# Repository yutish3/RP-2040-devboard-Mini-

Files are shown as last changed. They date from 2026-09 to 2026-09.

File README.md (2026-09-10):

### ABOUT 
rp-2040 dev board in small form factor of 3cm x 6cm made in kicad

it has :- 2 x 20 pin connectors , separate headers for HC - 05 Bluetooth module , extra 4Mb flash memory , USB c port , 2 buttons for BOOT and Reset and TC2030 connector for programming without usb c

# IMAGES

# SCHEMATICS 



# FOOTPRINTS



# PCB



# RENDER

Initially i tried to make it black but it changed color to smth random and it looks way cooler now 






# FILES
/Production folder has all the production files

/PCB files has all the pcb project files in it

# CREDITS

Kicad

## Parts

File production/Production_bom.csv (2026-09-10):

Designator | Footprint | Quantity | Value | LCSC Part #
C1, C2 | 0201 | 2 | 10uF
C10, C11, C12, C5, C6, C7, C8, C9 | 0201 | 8 | 100 nF
C13, C14 | 0201 | 2 | 15p
C15 | 0201 | 1 | 100nF
C3, C4 | 0201 | 2 | 1uF
D1 | 0402 | 1 | LED
J1 | USB_C_Receptacle_HCTL_HC-TYPE-C-16P-01A | 1 | USB_C_Receptacle_USB2.0_16P
J2 | Tag-Connect_TC2030-IDC-NL_2x03_P1.27mm_Vertical | 1 | SWD
J3 | PinHeader_1x06_P2.54mm_Vertical | 1 | HC-05
J5 | PinHeader_1x20_P2.54mm_Vertical | 1 | GPIO HEADERS - 1
J6 | PinHeader_1x20_P2.54mm_Vertical | 1 | GPIO HEADERS - 2
R1, R2 | 0201 | 2 | 27
R3, R4 | 0201 | 2 | 1K
R5 | 0201 | 1 | 10K
R6, R7 | 0201 | 2 | 5.1K
R8 | 0201 | 1 | 330
SW1 | SW_SPST_TS-1088-xR020 | 1 | RESET
SW2 | SW_SPST_TS-1088-xR020 | 1 | BOOT
U1 | QFN-56-1EP_7x7mm_P0.4mm_EP3.2x3.2mm | 1 | RP2040
U2 | SOIC-8_5.3x5.3mm_P1.27mm | 1 | W25Q32JVSS
U3 | SOT-223-3_TabPin2 | 1 | NCP1117-3.3_SOT223
U4 | SOT-666 | 1 | USBLC6-2P6
Y2 | Crystal_SMD_2520-4Pin_2.5x2.0mm | 1 | Crystal_GND24

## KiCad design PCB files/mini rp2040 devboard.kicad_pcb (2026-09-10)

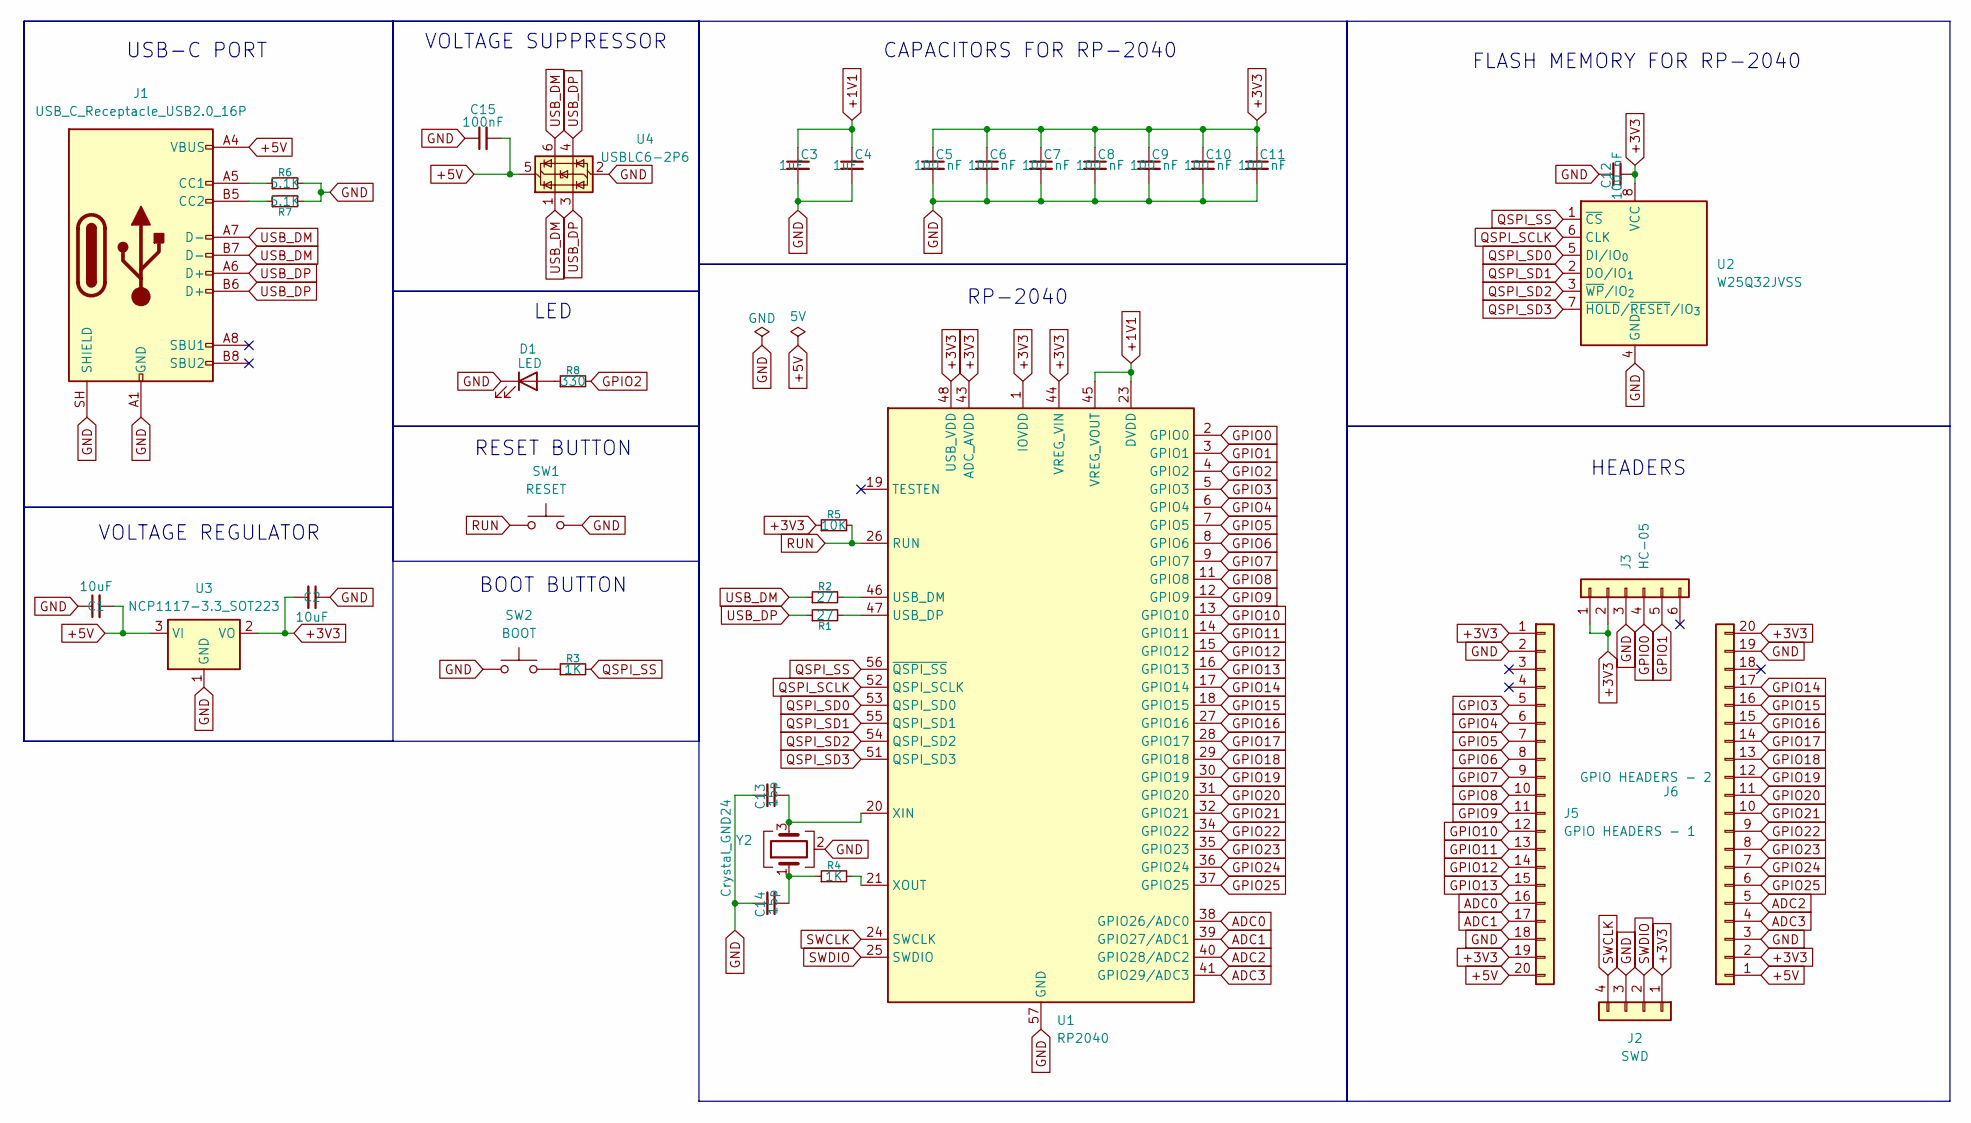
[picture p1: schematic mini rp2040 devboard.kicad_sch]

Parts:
C1, C2: 10uF; C_0201_0603Metric
C3, C4: 1uF; C_0201_0603Metric
C5, C6, C7, C8, C9, C10, C11, C12: 100 nF; C_0201_0603Metric
C13, C14: 15p; C_0201_0603Metric
C15: 100nF; C_0201_0603Metric
D1: LED; LED_0402_1005Metric
J1: USB_C_Receptacle_USB2.0_16P; USB_C_Receptacle_HCTL_HC-TYPE-C-16P-01A
J2: SWD; Tag-Connect_TC2030-IDC-NL_2x03_P1.27mm_Vertical
J3: HC-05; PinHeader_1x06_P2.54mm_Vertical
J5: GPIO HEADERS - 1; PinHeader_1x20_P2.54mm_Vertical
J6: GPIO HEADERS - 2; PinHeader_1x20_P2.54mm_Vertical
R1, R2: 27; R_0201_0603Metric
R3, R4: 1K; R_0201_0603Metric
R5: 10K; R_0201_0603Metric
R6, R7: 5.1K; R_0201_0603Metric
R8: 330; R_0201_0603Metric
SW1: RESET; SW_SPST_TS-1088-xR020
SW2: BOOT; SW_SPST_TS-1088-xR020
U1: RP2040; QFN-56-1EP_7x7mm_P0.4mm_EP3.2x3.2mm
U2: W25Q32JVSS; SOIC-8_5.3x5.3mm_P1.27mm
U3: NCP1117-3.3_SOT223; SOT-223-3_TabPin2
U4: USBLC6-2P6; SOT-666
Y2: Crystal_GND24; Crystal_SMD_2520-4Pin_2.5x2.0mm

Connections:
+1V1: C3.1, C4.1, U1.23 (DVDD), U1.45 (VREG_VOUT), U1.50 (DVDD)
+3V3: C2.2, C5.1, C6.1, C7.1, C8.1, C9.1, C10.1, C11.1, C12.1, J2.1, J3.1, J3.2, J5.1, J5.19, J6.2, J6.20, R5.1, U1.1 (IOVDD), U1.10 (IOVDD), U1.22 (IOVDD), U1.33 (IOVDD), U1.42 (IOVDD), U1.43 (ADC_AVDD), U1.44 (VREG_VIN), U1.48 (USB_VDD), U1.49 (IOVDD), U2.8 (VCC), U3.2 (VO)
+5V: C1.2, C15.2, J1.A4 (VBUS), J1.A9 (VBUS), J1.B4 (VBUS), J1.B9 (VBUS), J5.20, J6.1, U3.3 (VI), U4.5 (VBUS)
ADC0: J5.16, U1.38 (GPIO26/ADC0)
ADC1: J5.17, U1.39 (GPIO27/ADC1)
ADC2: J6.5, U1.40 (GPIO28/ADC2)
ADC3: J6.4, U1.41 (GPIO29/ADC3)
GND: C1.1, C2.1, C3.2, C4.2, C5.2, C6.2, C7.2, C8.2, C9.2, C10.2, C11.2, C12.2, C13.2, C14.2, C15.1, D1.1 (K), J1.A1 (GND), J1.A12 (GND), J1.B1 (GND), J1.B12 (GND), J1.SH (SHIELD), J2.3, J3.3, J5.2, J5.18, J6.3, J6.19, R6.2, R7.2, SW1.2, SW2.1, U1.57 (GND), U2.4 (GND), U3.1 (GND), U4.2 (GND), Y2.2 (G), Y2.4 (G)
GPIO0: J3.4, U1.2 (GPIO0)
GPIO1: J3.5, U1.3 (GPIO1)
GPIO2: R8.2, U1.4 (GPIO2)
GPIO3: J5.5, U1.5 (GPIO3)
GPIO4: J5.6, U1.6 (GPIO4)
GPIO5: J5.7, U1.7 (GPIO5)
GPIO6: J5.8, U1.8 (GPIO6)
GPIO7: J5.9, U1.9 (GPIO7)
GPIO8: J5.10, U1.11 (GPIO8)
GPIO9: J5.11, U1.12 (GPIO9)
GPIO10: J5.12, U1.13 (GPIO10)
GPIO11: J5.13, U1.14 (GPIO11)
GPIO12: J5.14, U1.15 (GPIO12)
GPIO13: J5.15, U1.16 (GPIO13)
GPIO14: J6.17, U1.17 (GPIO14)
GPIO15: J6.16, U1.18 (GPIO15)
GPIO16: J6.15, U1.27 (GPIO16)
GPIO17: J6.14, U1.28 (GPIO17)
GPIO18: J6.13, U1.29 (GPIO18)
GPIO19: J6.12, U1.30 (GPIO19)
GPIO20: J6.11, U1.31 (GPIO20)
GPIO21: J6.10, U1.32 (GPIO21)
GPIO22: J6.9, U1.34 (GPIO22)
GPIO23: J6.8, U1.35 (GPIO23)
GPIO24: J6.7, U1.36 (GPIO24)
GPIO25: J6.6, U1.37 (GPIO25)
unnamed: C14.1, R4.1, Y2.1
unnamed: D1.2 (A), R8.1
unnamed: J1.A5 (CC1), R6.1
unnamed: J1.B5 (CC2), R7.1
unnamed: R3.1, SW2.2
unnamed: R2.2, U1.46 (USB_DM)
unnamed: R1.2, U1.47 (USB_DP)
unnamed: C13.1, U1.20 (XIN), Y2.3
unnamed: R4.2, U1.21 (XOUT)
QSPI_SCLK: U1.52 (QSPI_SCLK), U2.6 (CLK)
QSPI_SD0: U1.53 (QSPI_SD0), U2.5 (DI/IO_{0})
QSPI_SD1: U1.55 (QSPI_SD1), U2.2 (DO/IO_{1})
QSPI_SD2: U1.54 (QSPI_SD2), U2.3 (~WP/IO_{2})
QSPI_SD3: U1.51 (QSPI_SD3), U2.7 (~HOLD/~RESET/IO_{3})
QSPI_SS: R3.2, U1.56 (~QSPI_SS), U2.1 (~CS)
RUN: R5.2, SW1.1, U1.26 (RUN)
SWCLK: J2.4, U1.24 (SWCLK)
SWDIO: J2.2, U1.25 (SWDIO)
USB_DM: J1.A7 (D-), J1.B7 (D-), R2.1, U4.1 (I/O1), U4.6 (I/O1)
USB_DP: J1.A6 (D+), J1.B6 (D+), R1.1, U4.3 (I/O2), U4.4 (I/O2)

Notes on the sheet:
FLASH MEMORY FOR RP-2040
RP-2040
BOOT BUTTON
USB-C PORT
RESET BUTTON
CAPACITORS FOR RP-2040
VOLTAGE REGULATOR
VOLTAGE SUPPRESSOR
LED
HEADERS

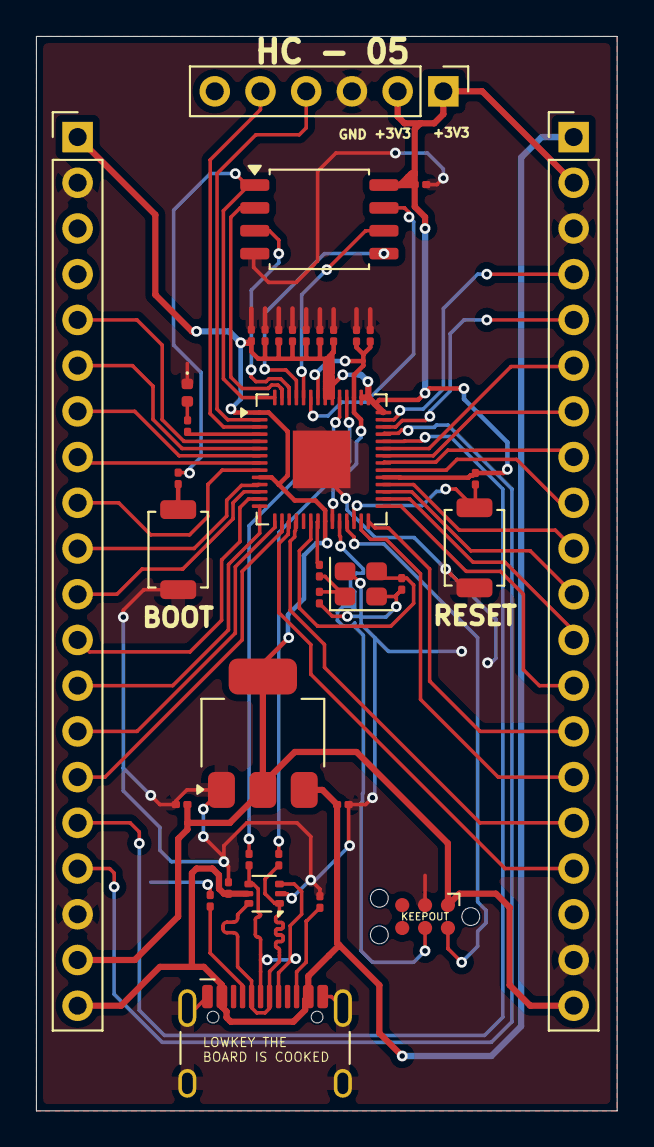
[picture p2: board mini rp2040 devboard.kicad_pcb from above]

Board: 2 copper layers, 32.3 x 59.7 mm, 36 parts (0 on the bottom side), 54 nets.
